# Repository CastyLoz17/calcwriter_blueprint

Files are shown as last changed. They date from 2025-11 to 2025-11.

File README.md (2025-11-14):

A hardware board that emulates keypresses on the keypad matrix of a Sharp EL-W531S II calculator.

## but... why tho?

So uh, once upon a bus ride home, I had a brain blast — a year before, I made math equations that mimicked computer logic ops like `AND`, `OR`, `NOT`, etc. Then I got spicy and added stuff like `SIGN`, `TO_BOOL`, and `EQUALS_TO`. I even hacked together `if` statements and pseudo-loops! but... I couldn’t store variables (tragic).

Eventually I realized I could abuse rounding errors and tangent’s cycly-ness to make storage actually _work_. Huge win. But typing those monster equations by hand? Pain. So the project died (rip scrap paper notes).

Then I wondered if a calculator could be turing complete (spoiler: no 💀), which spiraled into "what if I made it _automate itself_"? Thus, **Calcwriter** was born.

This project was mostly self-sponsored... until I found out that hackclub had blueprint ysws. Then I was like "wait why pay for chaos when I can get _sponsored_ for chaos?"

# Project Overview:

This board is split into two parts, mainly for modularity and also to cut costs for prototyping:

## 1. The logic board:

| Front | Back | Schematics |
| --- | --- | --- |
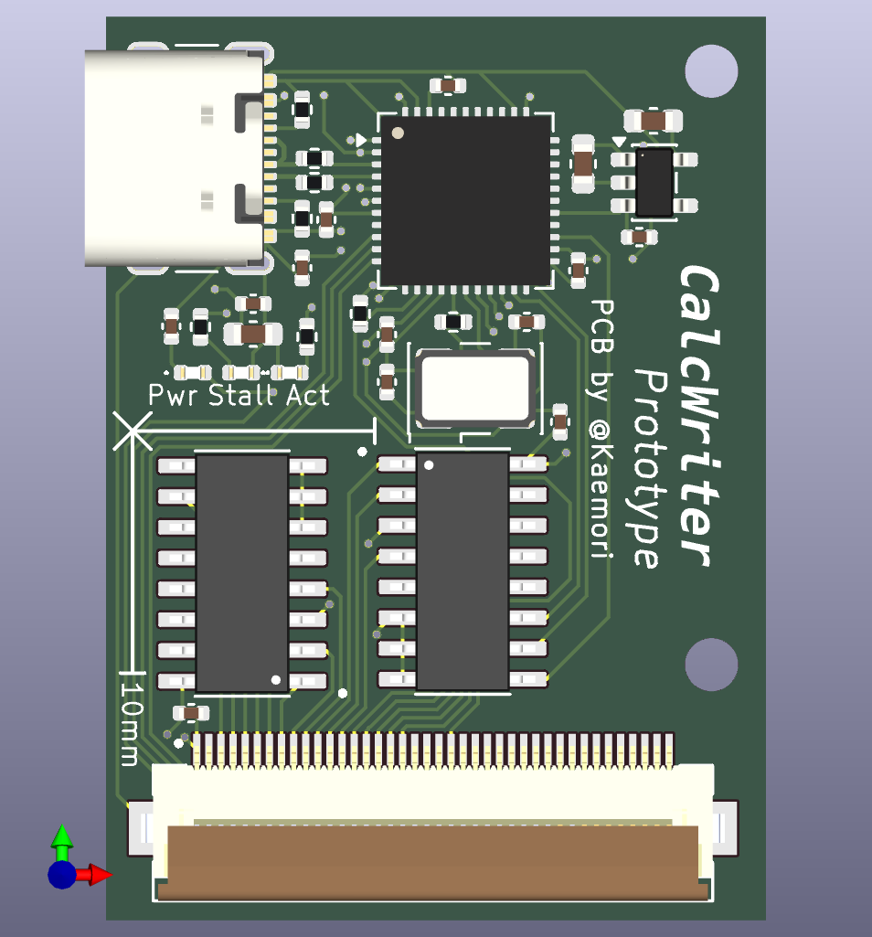
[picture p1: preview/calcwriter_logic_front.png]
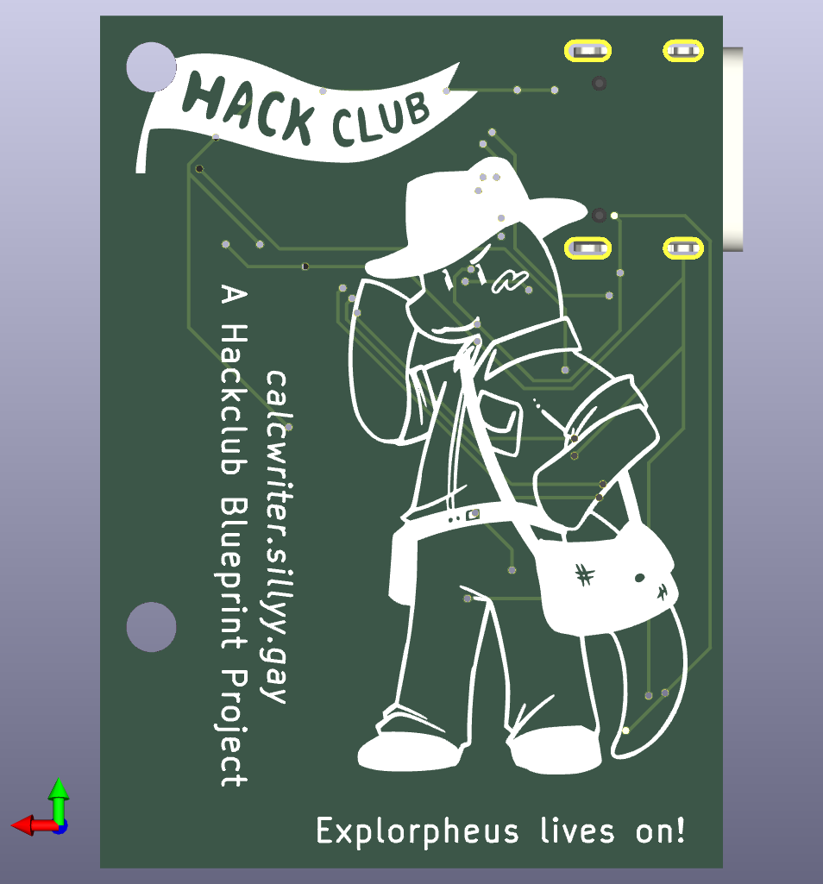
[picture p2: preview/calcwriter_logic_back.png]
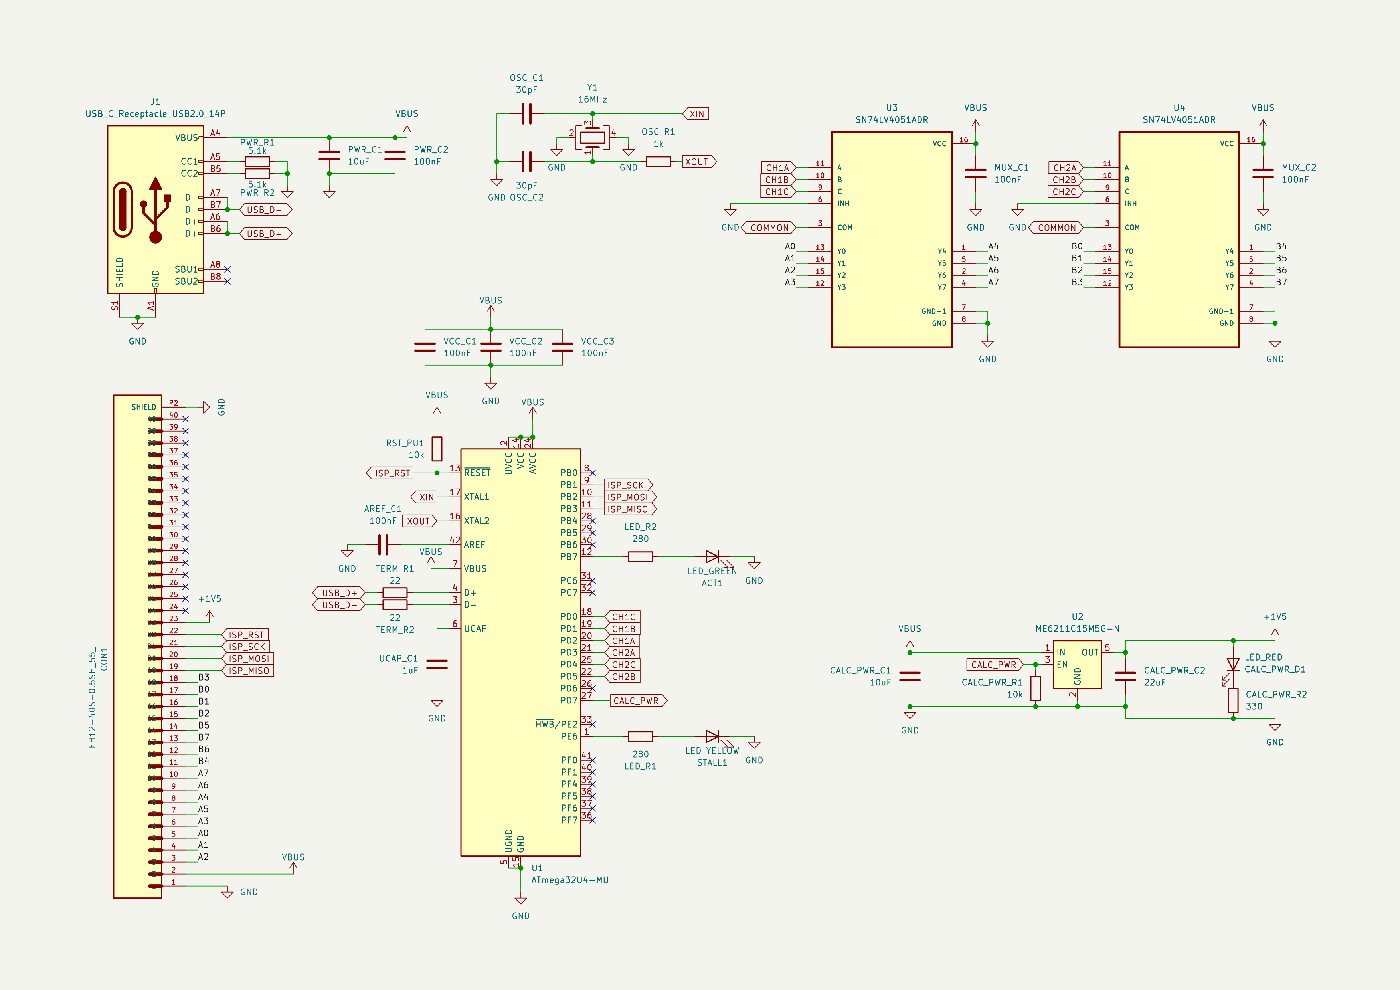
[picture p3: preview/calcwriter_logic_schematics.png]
|  |  |  |

The logic board is the main component, where all the calculations and inputs are actually happening. It is powered by an ATmega32U4 microcontroller and a bunch of SPST Analog Switches (MAX335CWGs) for controlling inputs. Equations will be sent over by the main device through a serial connection, which also powers the board.

## 2. The Interface board:

| Front | Back | Schematics |
| --- | --- | --- |
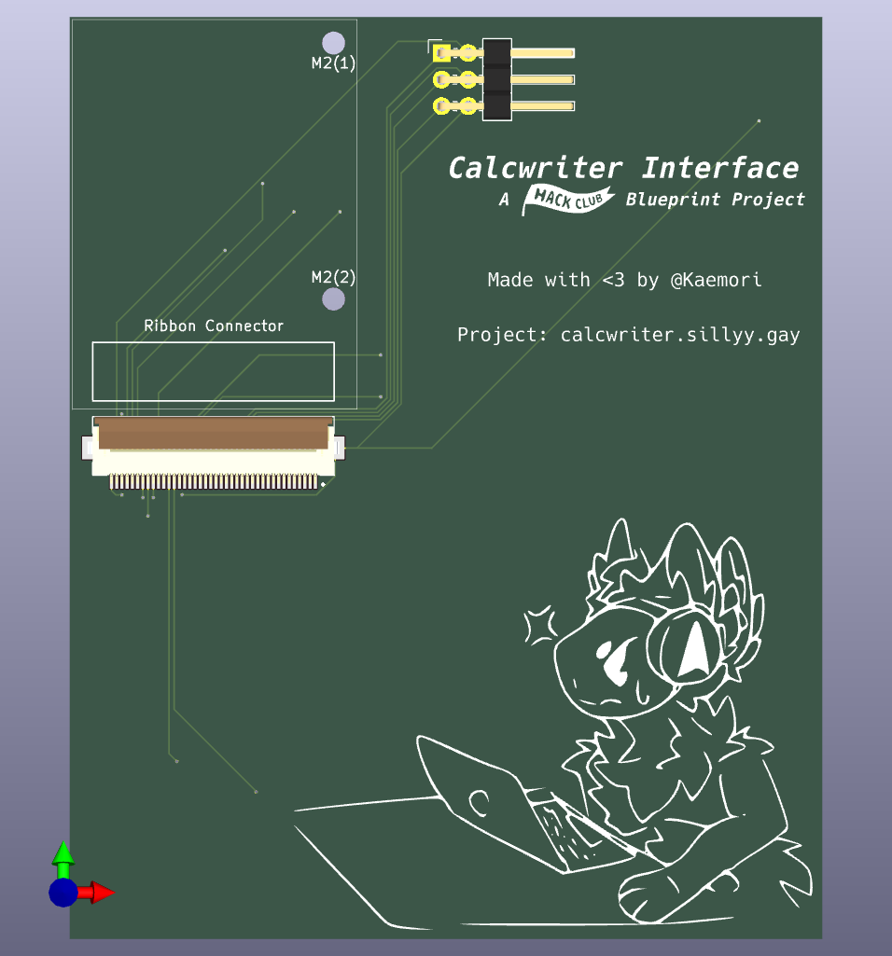
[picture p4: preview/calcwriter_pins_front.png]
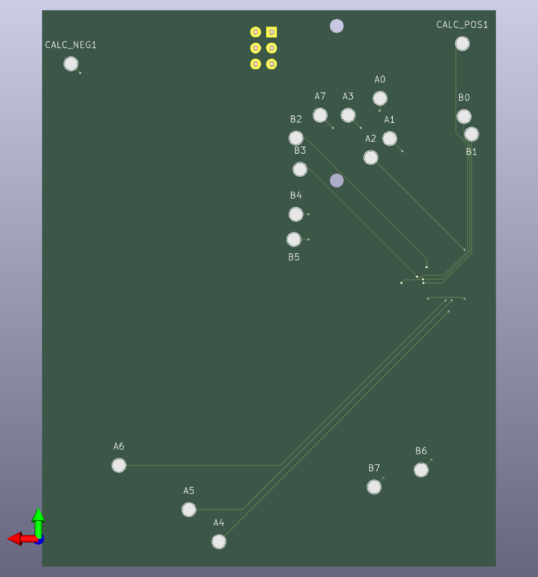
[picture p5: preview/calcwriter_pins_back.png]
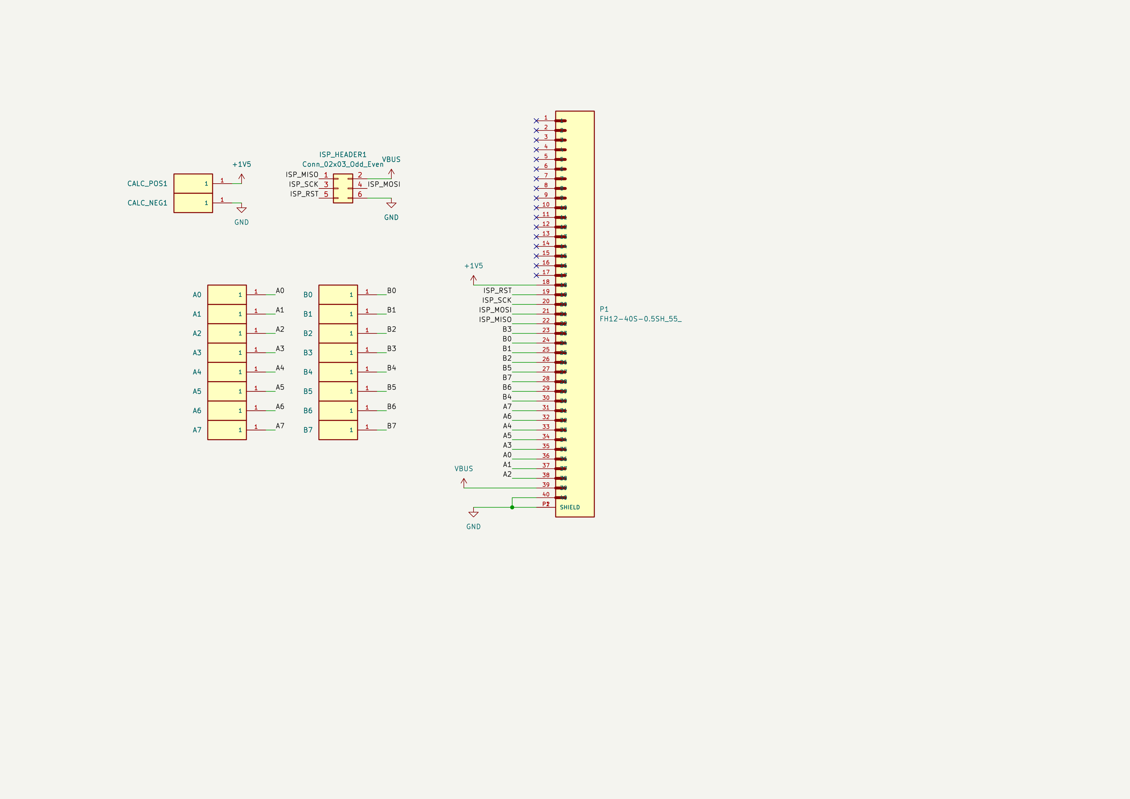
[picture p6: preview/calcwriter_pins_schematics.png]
|  |  |  |

The interface board is the board that connects the logic board to the calculator. It has 31 input pogo pins, as well as 2 power supply pins, each precisely placed such that when the board is placed onto the calculator, the pogo pins connects to the matrix vias of the calculator. The connections are then extended up through a ribbon cable into the logic board for the actual controlling part. The interface board provides power to the calculator, and also provides an ISP interface to program the ATmega32U4. This part is seperated as it allows my logic board to stay as small as possible, and also to make it so that I dont have to waste a lot of money on 4 layers of mostly just empty boards and pogo pins.

# Bill Of Material:

later

TODO: remember to write basic firmware for the board. remember to print out both boards for scale. remember to make a case for the calculator, and the board.

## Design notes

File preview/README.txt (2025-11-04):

This folder contains the PDF of the schematics, as well as the top and bottom view of both boards.

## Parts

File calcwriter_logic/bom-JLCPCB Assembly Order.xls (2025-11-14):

JLCPCB BOM Tool - BOM Matching
BOM name：bom-JLCPCB Assembly Order.xlsx |  |  | Download Time：2025-11-14 10:50:27 |  |  |  | * Our matching results are updated in real-time, but stock and prices may change. If it's been over 24 hours, please re-match before placing your order.
PCB Assembled Qty：5 |  |  | Est. Total Price：14.9566
Your BOM |  |  |  |  | Matched Parts |  |  |  |  |  |  | Order Information
Top Designator | Bottom Designator | Comment | Footprint | JLCPCB Part # | Matches | Part # | Manufacturer | Footprint | Description | Category | Warning | JLCPCB Part # | Product link | Lib Type | Qty | Source | Total Price ($)
ACT1 |  | LED_GREEN | 0402 |  | Select by Customer | NCD0402G1 | Foshan NationStar Optoelectronics | 0402 | -30℃~+85℃ 130° 2.6V~3.6V 20mA 270mcd 515nm~530nm 520nm 72mW Emerald Green 0402 LED Indication - Discrete ROHS | LED Indication - Discrete |  | C130723 | https://jlcpcb.com/partdetail/142012-NCD0402G1/C130723 | Extended | 6 | 6 JLCPCB | 0.2358
AREF_C1,MUX_C1,MUX_C2,PWR_C2,VCC_C1,VCC_C2,VCC_C3 |  | 100nF | 0402 |  | Select by Customer | CL05B104KO5NNNC | Samsung Electro-Mechanics | 0402 | 100nF 16V X7R ±10% 0402 Multilayer Ceramic Capacitors MLCC - SMD/SMT ROHS | Multilayer Ceramic Capacitors MLCC - SMD/SMT | 1.There may be multiple types of parts, but one type of part has been matched. Please check.; | C1525 | https://jlcpcb.com/partdetail/1877-CL05B104KO5NNNC/C1525 | Basic | 14 | 14 JLCPCB | 0.0168
CALC_PWR_C1,PWR_C1 |  | 10uF | 0603 |  | Select by Customer | CL10A106MQ8NNNC | Samsung Electro-Mechanics | 0603 | 10uF 6.3V X5R ±20% 0603 Multilayer Ceramic Capacitors MLCC - SMD/SMT ROHS | Multilayer Ceramic Capacitors MLCC - SMD/SMT | 1.There may be multiple types of parts, but one type of part has been matched. Please check.; | C1691 | https://jlcpcb.com/partdetail/2043-CL10A106MQ8NNNC/C1691 | Extended | 20 | 20 JLCPCB | 0.092
CALC_PWR_C2 |  | 22uF | 0603 |  | Select by System | CL10A226MQ8NRNC | Samsung Electro-Mechanics | 0603 | 22uF 6.3V X5R ±20% 0603 Multilayer Ceramic Capacitors MLCC - SMD/SMT ROHS | Multilayer Ceramic Capacitors MLCC - SMD/SMT |  | C59461 | https://jlcpcb.com/partdetail/60514-CL10A226MQ8NRNC/C59461 | Basic | 2 | 2 JLCPCB | 0.0174
CALC_PWR_D1 |  | LED_RED | 0402 |  | Select by Customer | NCD0402R1 | Foshan NationStar Optoelectronics | 0402 | -30℃~+85℃ 1.6V~2.6V 130° 25mA 30mcd 615nm~635nm 630nm 65mW Red 0402 LED Indication - Discrete ROHS | LED Indication - Discrete |  | C130719 | https://jlcpcb.com/partdetail/142008-NCD0402R1/C130719 | Extended | 7 | 7 JLCPCB | 0.2471
CALC_PWR_R1,RST_PU1 |  | 10k | 0402 |  | Select by Customer | 0402WGF1002TCE | UNI-ROYAL(Uniroyal Elec) | 0402 | -55℃~+155℃ 10kΩ 50V 62.5mW Thick Film Resistor ±1% ±100ppm/℃ 0402 Chip Resistor - Surface Mount ROHS | Chip Resistor - Surface Mount | 1.There may be multiple types of parts, but one type of part has been matched. Please check.; | C25744 | https://jlcpcb.com/partdetail/26487-0402WGF1002TCE/C25744 | Basic | 4 | 4 JLCPCB | 0.0024
CALC_PWR_R2 |  | 330 | 0402 |  | Select by Customer | 0402WGF3300TCE | UNI-ROYAL(Uniroyal Elec) | 0402 | -55℃~+155℃ 330Ω 50V 62.5mW Thick Film Resistor ±1% ±100ppm/℃ 0402 Chip Resistor - Surface Mount ROHS | Chip Resistor - Surface Mount | 1.The comment (0402WGF3300TCE) of this part does not match the one (330) provided in your BOM. Please confirm; | C25104 | https://jlcpcb.com/partdetail/25847-0402WGF3300TCE/C25104 | Basic | 2 | 2 JLCPCB | 0.0014
CON1 |  | FH12-40S-0.5SH_55_ | HRS_FH12-40S-0.5SH_55_ |  | Select by Customer | FH12-40S-0.5SH(55) | HRS(Hirose) | SMD,P=0.5mm,卧贴 | -40℃~+85℃ 0.3mm 0.5mm 2mm 40P Bottom Contact Gold Hinged Lid Phosphor Bronze Surface Mount, Right Angle SMD,P=0.5mm,Surface Mount，Right Angle FFC, FPC (Flat Flexible) Connector Assemblies ROHS | FFC, FPC (Flat Flexible) Connector Assemblies | 1.The comment (FH12-40S-0.5SH(55)) of this part does not match the one (FH12-40S-0.5SH_55_) provided in your BOM. Please confirm; | C202114 | https://jlcpcb.com/partdetail/HRS_Hirose-FH12_40S_0_5SH_55/C202114 | Extended | 2 | 2 JLCPCB | 1.302
J1 |  | USB_C_Receptacle_USB2.0_14P | USB_C_Receptacle_GCT_USB4105-xx-A_16P_TopMnt_Horizontal |  | Select by Customer | TYPE-C16PIN | SHOU HAN | SMD | -40℃~+85℃ 1 10,000 Cycles 16P 30V 3A Black Female Surface Mount, Right Angle Type-C SMD USB Connectors ROHS | USB Connectors |  | C393939 | https://jlcpcb.com/partdetail/SHOUHAN-TYPEC16PIN/C393939 | Extended | 2 | 2 JLCPCB | 0.1288
LED_R1,LED_R2 |  | 280 | 0402 |  | Select by Customer | 0402WGF2800TCE | UNI-ROYAL(Uniroyal Elec) | 0402 | -55℃~+155℃ 280Ω 50V 62.5mW Thick Film Resistor ±1% ±100ppm/℃ 0402 Chip Resistor - Surface Mount ROHS | Chip Resistor - Surface Mount | 1.The comment (0402WGF2800TCE) of this part does not match the one (280) provided in your BOM. Please confirm; | C423200 | https://jlcpcb.com/partdetail/416150-0402WGF2800TCE/C423200 | Extended | 20 | 20 JLCPCB | 0.014
OSC_C1,OSC_C2 |  | 30pF | 0402 |  | Select by Customer | 0402CG300J500NT | FH (Guangdong Fenghua Advanced Tech) | 0402 | 30pF 50V C0G ±5% 0402 Multilayer Ceramic Capacitors MLCC - SMD/SMT ROHS | Multilayer Ceramic Capacitors MLCC - SMD/SMT |  | C1570 | https://jlcpcb.com/partdetail/1922-0402CG300J500NT/C1570 | Extended | 20 | 20 JLCPCB | 0.022
OSC_R1 |  | 1k | 0402 |  | Select by System | 0402WGF1001TCE | UNI-ROYAL(Uniroyal Elec) | 0402 | -55℃~+155℃ 1kΩ 50V 62.5mW Thick Film Resistor ±1% ±100ppm/℃ 0402 Chip Resistor - Surface Mount ROHS | Chip Resistor - Surface Mount |  | C11702 | https://jlcpcb.com/partdetail/12256-0402WGF1001TCE/C11702 | Basic | 2 | 2 JLCPCB | 0.0012
PWR_R1,PWR_R2 |  | 5.1k | 0402 |  | Select by System | 0402WGF5101TCE | UNI-ROYAL(Uniroyal Elec) | 0402 | -55℃~+155℃ 5.1kΩ 50V 62.5mW Thick Film Resistor ±1% ±100ppm/℃ 0402 Chip Resistor - Surface Mount ROHS | Chip Resistor - Surface Mount |  | C25905 | https://jlcpcb.com/partdetail/26648-0402WGF5101TCE/C25905 | Basic | 4 | 4 JLCPCB | 0.002
STALL1 |  | LED_YELLOW | 0402 |  | Select by Customer | NCD0402O1 | Foshan NationStar Optoelectronics | 0402 | -30℃~+85℃ 1.6V~2.6V 130° 20mcd~45mcd 25mA 598nm~610nm 65mW Discrete Diode Orange 0402 LED Indication - Discrete ROHS | LED Indication - Discrete |  | C130720 | https://jlcpcb.com/partdetail/142009-NCD0402O1/C130720 | Extended | 7 | 7 JLCPCB | 0.2814
TERM_R1,TERM_R2 |  | 22 | 0402 |  | Select by Customer | 0402WGF220JTCE | UNI-ROYAL(Uniroyal Elec) | 0402 | -55℃~+155℃ 22Ω 50V 62.5mW Thick Film Resistor ±1% ±100ppm/℃ 0402 Chip Resistor - Surface Mount ROHS | Chip Resistor - Surface Mount | 1.The comment (0402WGF220JTCE) of this part does not match the one (22) provided in your BOM. Please confirm; | C25092 | https://jlcpcb.com/partdetail/25835-0402WGF220JTCE/C25092 | Basic | 4 | 4 JLCPCB | 0.0024
U1 |  | ATmega32U4-A | QFN-44-1EP_7x7mm_P0.5mm_EP5.15x5.15mm |  | Select by Customer | ATMEGA32U4-MU | Microchip Tech | VQFN-44-EP(7x7) | 10bit 16MHz 2.7V~5.5V 26 32KB AVR FLASH VQFN-44-EP(7x7) Microcontrollers (MCU/MPU/SOC) ROHS | Microcontrollers (MCU/MPU/SOC) |  | C112161 | https://jlcpcb.com/partdetail/MicrochipTech-ATMEGA32U4MU/C112161 | Extended | 2 | 2 JLCPCB | 10.239
U2 |  | ME6211C15M5G-N | SOT-23-5 |  | Select by System | ME6211C15M5G-N | MICRONE(Nanjing Micro One Elec) | SOT-23-5 | -40℃~+85℃ 1 1.5V 300mA 6V 70dB@(1kHz) Enable Fixed Positive SOT-23-5 Voltage Regulators - Linear, Low Drop Out (LDO) Regulators ROHS | Voltage Regulators - Linear, Low Drop Out (LDO) Regulators |  | C53100 | https://jlcpcb.com/partdetail/54116-ME6211C15M5GN/C53100 | Extended | 6 | 6 JLCPCB | 0.2862
U3,U4 |  | SN74LV4051ADR | SOIC127P600X175-16N |  | Select by System | SN74LV4051ADR | Texas Instruments | SOIC-16 | -40℃~+85℃ 1 22Ω 2V~5.5V 35MHz 600ps 8:1 SOIC-16 Analog Switches, Multiplexers ROHS | Analog Switches, Multiplexers |  | C128414 | https://jlcpcb.com/partdetail/TexasInstruments-SN74LV4051ADR/C128414 | Extended | 4 | 4 JLCPCB | 0.9764
UCAP_C1 |  | 1uF | 0402 |  | Select by System | CL05A105KA5NQNC | Samsung Electro-Mechanics | 0402 | 1uF 25V X5R ±10% 0402 Multilayer Ceramic Capacitors MLCC - SMD/SMT ROHS | Multilayer Ceramic Capacitors MLCC - SMD/SMT |  | C52923 | https://jlcpcb.com/partdetail/53938-CL05A105KA5NQNC/C52923 | Basic | 2 | 2 JLCPCB | 0.0058
Y1 |  | 16MHz | Crystal_SMD_5032-4Pin_5.0x3.2mm |  | Select by Customer | XL1EL89CSI-111YLC-16M | YXC Crystal Oscillators | SMD5032-4P | -40℃~+85℃ 16MHz 20pF Crystal Oscillator ±10ppm ±20ppm SMD5032-4P Crystals ROHS | Crystals |  | C18214305 | https://jlcpcb.com/partdetail/19392654-XL1EL89CSI_111YLC16M/C18214305 | Extended | 5 | 5 JLCPCB | 1.0825

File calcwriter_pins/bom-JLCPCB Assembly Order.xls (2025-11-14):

JLCPCB BOM Tool - BOM Matching
BOM name：bom-JLCPCB Assembly Order.xlsx |  |  | Download Time：2025-11-14 11:09:23 |  |  |  | * Our matching results are updated in real-time, but stock and prices may change. If it's been over 24 hours, please re-match before placing your order.
PCB Assembled Qty：5 |  |  | Est. Total Price：4.5900
Your BOM |  |  |  |  | Matched Parts |  |  |  |  |  |  | Order Information
Top Designator | Bottom Designator | Comment | Footprint | JLCPCB Part # | Matches | Part # | Manufacturer | Footprint | Description | Category | Warning | JLCPCB Part # | Product link | Lib Type | Qty | Source | Total Price ($)
 | A0,A1,A2,A3,A4,A5,A6,A7,B0,B1,B2,B3,B4,B5,B6,B7,CALC_NEG1,CALC_POS1 | 0965-0-15-20-80-14-11-0 | YZR0156-20033-02 |  | Select by Customer | YZR0156-20033-02 | Xinyangze | - | -20℃~+70℃ 10,000 Cycles 12V 1A 1P 2.8mm 3.3mm 50mΩ Brass Gold Pogo Pin - Pogo Pin Spring Probe Connector ROHS | Pogo Pin Spring Probe Connector | 1.The comment (YZR0156-20033-02) of this part does not match the one (0965-0-15-20-80-14-11-0) provided in your BOM. Please confirm; 2.There may be multiple types of parts, but one type of part has been matched. Please check.; | C7429448 | https://jlcpcb.com/partdetail/Xinyangze-YZR0156_2003302/C7429448 | Extended | 36 | 36 JLCPCB | 4.59

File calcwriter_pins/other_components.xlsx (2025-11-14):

Digi-Key: Shopping Cart
Index | Quantity | Part Number | Manufacturer Part Number | Description | Customer Reference | Available | Backorder | Unit Price | Extended Price USD
1 | 1 | HFK140CT-ND | FH12A-40S-0.5SH(55) | CONN FFC FPC TOP 40POS 0.5MM R/A |  | 1 | 0 | 2.3 | 2.30
2 | 1 | 952-2092-ND | M20-9950345 | CONN HEADER R/A 6POS 2.54MM |  | 1 | 0 | 0.35 | 0.35

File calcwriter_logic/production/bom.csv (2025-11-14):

Designator | Footprint | Quantity | Value | LCSC Part #
ACT1 | 0402 | 1 | LED_GREEN
AREF_C1, MUX_C1, MUX_C2, PWR_C2, VCC_C1, VCC_C2, VCC_C3 | 0402 | 7 | 100nF
CALC_PWR_C1, PWR_C1 | 0603 | 2 | 10uF
CALC_PWR_C2 | 0603 | 1 | 22uF
CALC_PWR_D1 | 0402 | 1 | LED_RED
CALC_PWR_R1, RST_PU1 | 0402 | 2 | 10k
CALC_PWR_R2 | 0402 | 1 | 330
CON1 | HRS_FH12-40S-0.5SH_55_ | 1 | FH12-40S-0.5SH_55_
J1 | USB_C_Receptacle_GCT_USB4105-xx-A_16P_TopMnt_Horizontal | 1 | USB_C_Receptacle_USB2.0_14P
LED_R1, LED_R2 | 0402 | 2 | 280
OSC_C1, OSC_C2 | 0402 | 2 | 30pF
OSC_R1 | 0402 | 1 | 1k
PWR_R1, PWR_R2 | 0402 | 2 | 5.1k
STALL1 | 0402 | 1 | LED_YELLOW
TERM_R1, TERM_R2 | 0402 | 2 | 22
U1 | QFN-44-1EP_7x7mm_P0.5mm_EP5.15x5.15mm | 1 | ATmega32U4-MU
U2 | SOT-23-5 | 1 | ME6211C15M5G-N
U3, U4 | SOIC127P600X175-16N | 2 | SN74LV4051ADR
UCAP_C1 | 0402 | 1 | 1uF
Y1 | Crystal_SMD_5032-4Pin_5.0x3.2mm | 1 | 16MHz

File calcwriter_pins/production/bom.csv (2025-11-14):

Designator | Footprint | Quantity | Value | LCSC Part #
A0, A1, A2, A3, A4, A5, A6, A7, B0, B1, B2, B3, B4, B5, B6, B7, CALC_NEG1, CALC_POS1 | YZR0156-20033-02 | 18 | 0965-0-15-20-80-14-11-0
ISP_HEADER1 | PinHeader_2x03_P2.54mm_Horizontal | 1 | Conn_02x03_Odd_Even
P1 | HRS_FH12-40S-0.5SH_55_ | 1 | FH12-40S-0.5SH_55_

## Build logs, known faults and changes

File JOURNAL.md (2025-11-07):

<!--
  ===================    !!READ THIS NOTICE!!   ====================
  DO NOT edit this file manually. Your changes WILL BE OVERWRITTEN!
  This journal is auto generated and updated by Hack Club Blueprint.
  To edit this file, please edit your journal entries on Blueprint.
  ==================================================================
-->

## 10/25/2025 3 PM - Joined Blueprint! Updated my Blueprint with current progress  

I started this project like two weeks ago as a my first PCB project, and only now did I realize there was a YSWS for this exact thing lmfao.
When I started this project, I hooked up Hackatime to my KiCad, and made a nice little schematic for this, and also started routing this board. The schematic is just an Arduino Micro Pro, connected to three PCF8575s, that then routes into 10 CD4066s. This is then hooked into a common bus and a ribbon connector, which is supposed to short two pins of the matrix at a time. The 10 CD4066s are insane to route, so I'm currently trying to find another SPST chip that isn't a bajillion dollars. This is still an improvement from my previous plan of 90 MOSFET switches for my first prototype! Schematics attached below!



## 10/25/2025 6 PM - Redesigned PCB!  

I did not like the crowded method of having a PCF8575 IC expander that then connects into CD4066s, so I did the logical thing and went hunting for a higher channel capacity SPST switch, which lead me to find the (relatively) cheap MAX335, a chip with 8 seperately controlled SPST switches (double what the CD4066 had, with only 4 SPST switches), and ALSO support daisy chaining (using the SPI interface instead of the I2C interface the PFC8575 used), which halved the amount of analog switch chips I needed, and also removed the need for the PFC8575 chips since everything is daisy-chained! Now I need to actually do routing lmao.
OH YEAH ALSO i added decaps. very silly.
Schematics attached below!


## 10/26/2025 1 PM - Routed the PCB  

This was two days of my life, mostly because of the fact that I have never done anything like this before (not even the "Hello world" of PCBCADing, I skipped the humble LED + Resistor intro and dived DIRECTLY INTO WHATEVER THIS IS!)


My routing is a bit horrible but I managed to get this done at last. I also learnt about the existence of power and ground fills (and how it's SUPPOSED to reduce interference?) so like I used them in the GND and VCC layers of my board!
PCB attached below:


## 10/26/2025 2 PM - Cleaned up the PCB  

I'm writing this in a haste. I redid some of the connections that looked weird or that could be optimized, and stuck the branding on there as well. Reminder to self to start taking measurements and finish the pogo board by today, as well as silkscreen the github urb and credits onto the board.



## 10/27/2025 - Made the second board and cleaned up the PCB (Pt. 2)  

I did all the required measurements for the second interface board that is supposed to make the connection between the calculator and my logic board... even made a script that explores the best possible arrangement for the pins such that there wouldn't be any overlaps between the routing:

Script here:


After that, I read through the devboard tutorial and realized I made many bad PCB mistakes (e.g. not dogbone'ing my vias, caps way bigger than required, yada yada)... so I redid my routing. it still has many problems with it but I'm just so done with PCBing for today:


Maybe I'll tank tonight out and fix up my horrible choices? I don't know... I have a robotics competition tomorrow...  

## 10/28/2025 - Readme'ing and DNSing  

I wrote a nice little readme on my github page, and spent another good portion of today night to make both https://calcwriter.sillyy.gay and http://calcwriter.sillyy.gay redirect to https://github.com/CastyLoz17/calcwriter_blueprint using Cloudfare. This took way too long. I suck at DNS records. This sucks.


note to self to clean up pcb after I return from tomorrow's competition.  

## 10/29/2025 - Swapped Arduino out for SOC  

Title says it all! I swapped the Sparkfun Micro Pro with a SOC (More specifically, the ATmega32U4) to be put directly onto the board! Right now though, its just the schematics only, and I haven't wired the main components yet (e.g. Only connected the USB-C header and crystal oscillator)

Also, before that, I cleaned up my PCB for the... I-don't-even-know-anymore-th time... so theres that!
Tomorrow, I'll work on reworking my old SPST Analog Switches with absolutely horrible wiring, with some new schematics with nets and stuff, connect the SOC to the Analog Switches, and maaaybe start working on connecting the SOC to the main board if I have the time?
I also realized my Interface board was in the wrong orientation, and had to be flipped over. I was SOOOO close to hand-doing it until my lord and savior Keyaan said that I could just move components from one side of the board to the other side, and vice versa. This tip helped me save so much time, I CANNOT thank you enough!
All in all a very long day (Microchip Technologies make HORRIBLE docs), but I'm glad I got things done.  

## 10/30/2025 - Swapped Arduino out for SOC (on the PCB!)  

I have gone TOO long without writing a journal entry, and it's ITCHING ASKJFHAJLFHSDKJFHAL
I've done a LOT in the past 2 days:
- Finished and cleaned up Schematics
- Swapped out the Arduino out for a ATmega32U4
- REwired my PCB because I changed some stuff in the schematics

The following is... TWO WHOLE DAMN DAYS OF WORK!


Next up, I'll optimize the PCB, and then ship this project!
also, say hi to Goober!


p.s. Don't mind the mismatched holes at the top, I forgot to refill copper fills before taking a screenshot and am too lazy to fix.  

## 10/31/2025 - Fixed some mistakes, made vias bigger (for cost efficiency)  

So... apparently my board was not cost-efficient as I had to use 0.15mm via hole sizes, and the blueprint people were not too happy about that. The base via hole size JLC offers is 0.3mm hole size, so I had to go through and change every via to be double its size! AAAAND then I did one final sanity check and realized I have been using a 48 pin chip instead of the 44 pin I should be using, which means I had to redo the SOC since it was the wrong footprint. At long last this (should) be done! unless... I figure out how to remove the last horizontal CD4066 chip somehow? that would make my board way shorter... if only there was a way to employ the GPIO pins... I'll think about this overnight

PCB below!:


## 11/3/2025 - light rerouting and some styling  

explorpheus!



i also did a bit of cleaning up (again), made the board a biiitt shorter and way more appealing. also printed the outline out using my 3d printer and i like the size! thats silly heh
welp theres nothing left to do except writing the github and also some simple blinky firmware and then shipping! 4 days till november 7th and im proud of meh speed!

## 11/7/2025 - complete reroute, cutting costs, shrinking board (and more!)  

below you see 18 hours of work in one screenshot!


for starters, you might see that the board is different. thats because i completely rerouted everything!! after a bit of tinkering on my calculator board with my multimeter, i found out that there were (at least) 8 pairs of vias that are internally connected! and 8 is also how many channels one MAX335 chip offers. this gave me a way to completely remove the 5th chip at the bottom, reducing my board's vertical length and wiring complexity! these newly opened channels also provided me a way to connect the ISP headers AND the calculator power supply directly to the interface board using ribbon cables (_6 + 1 = 7_ channels for this, just about how much channels i freed. that gives me 31 + 7 = 38 channels, 2 less than the 40 that my ribbon cable offers)! this also meant i could remove the pads for the ISP and calculator power, which further reduced the height of my board!

now, all thats left to do is to redo my interface board, do a final sanity check and a cleanup, then update my github! lowkey proud of myself, since this is my _first damn pcb project_ :3

(p.s. i also spent like 3 hours compiling and recompiling my bom after every change, but since that was time i could have saved if i wasnt so anxious, i didnt count it. this 18 hours is just me testing my calculator and redesigning my board)  

## 11/8/2025 - updated schematics!  

the schematics have been updated to reflect the new ribbon cable connections!

i also switched the HORRIBLE schematics i did and replaced the connections with nets! now time for the PCB... siiighhhh

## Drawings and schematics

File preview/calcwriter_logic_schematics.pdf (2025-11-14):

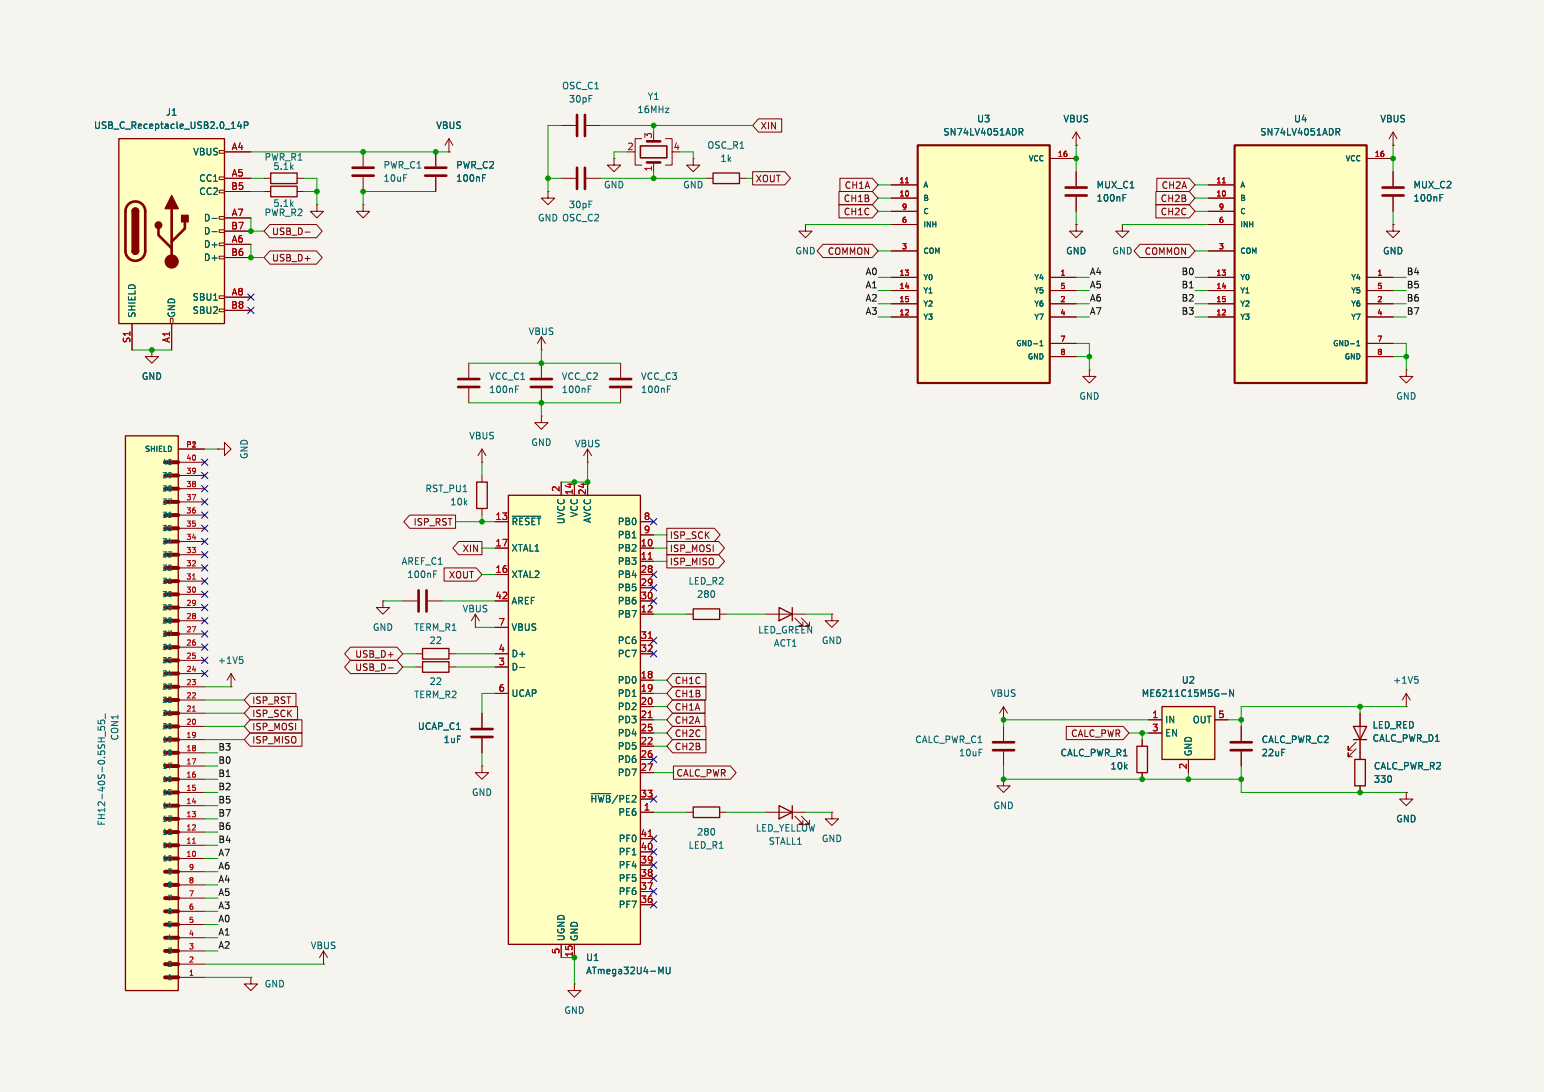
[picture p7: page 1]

5 VCC 14 GND 15 AVCC 24 PB0 8 PB1 9 PB2 10 PB3 11 PB4 28 PB5 29 PB6 30 PB7 12 PC6 31 PC7 32 PD0 18 PD1 19 PD2 20 PD3 21 PD4 25 PD5 22 PD6 26 PD7 27 ~{HWB}/PE233 PE6 1 PF0 41 PF1 40 PF4 39 PF5 38 PF6 37 PF7 36 U1ATmega32U4-MU

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

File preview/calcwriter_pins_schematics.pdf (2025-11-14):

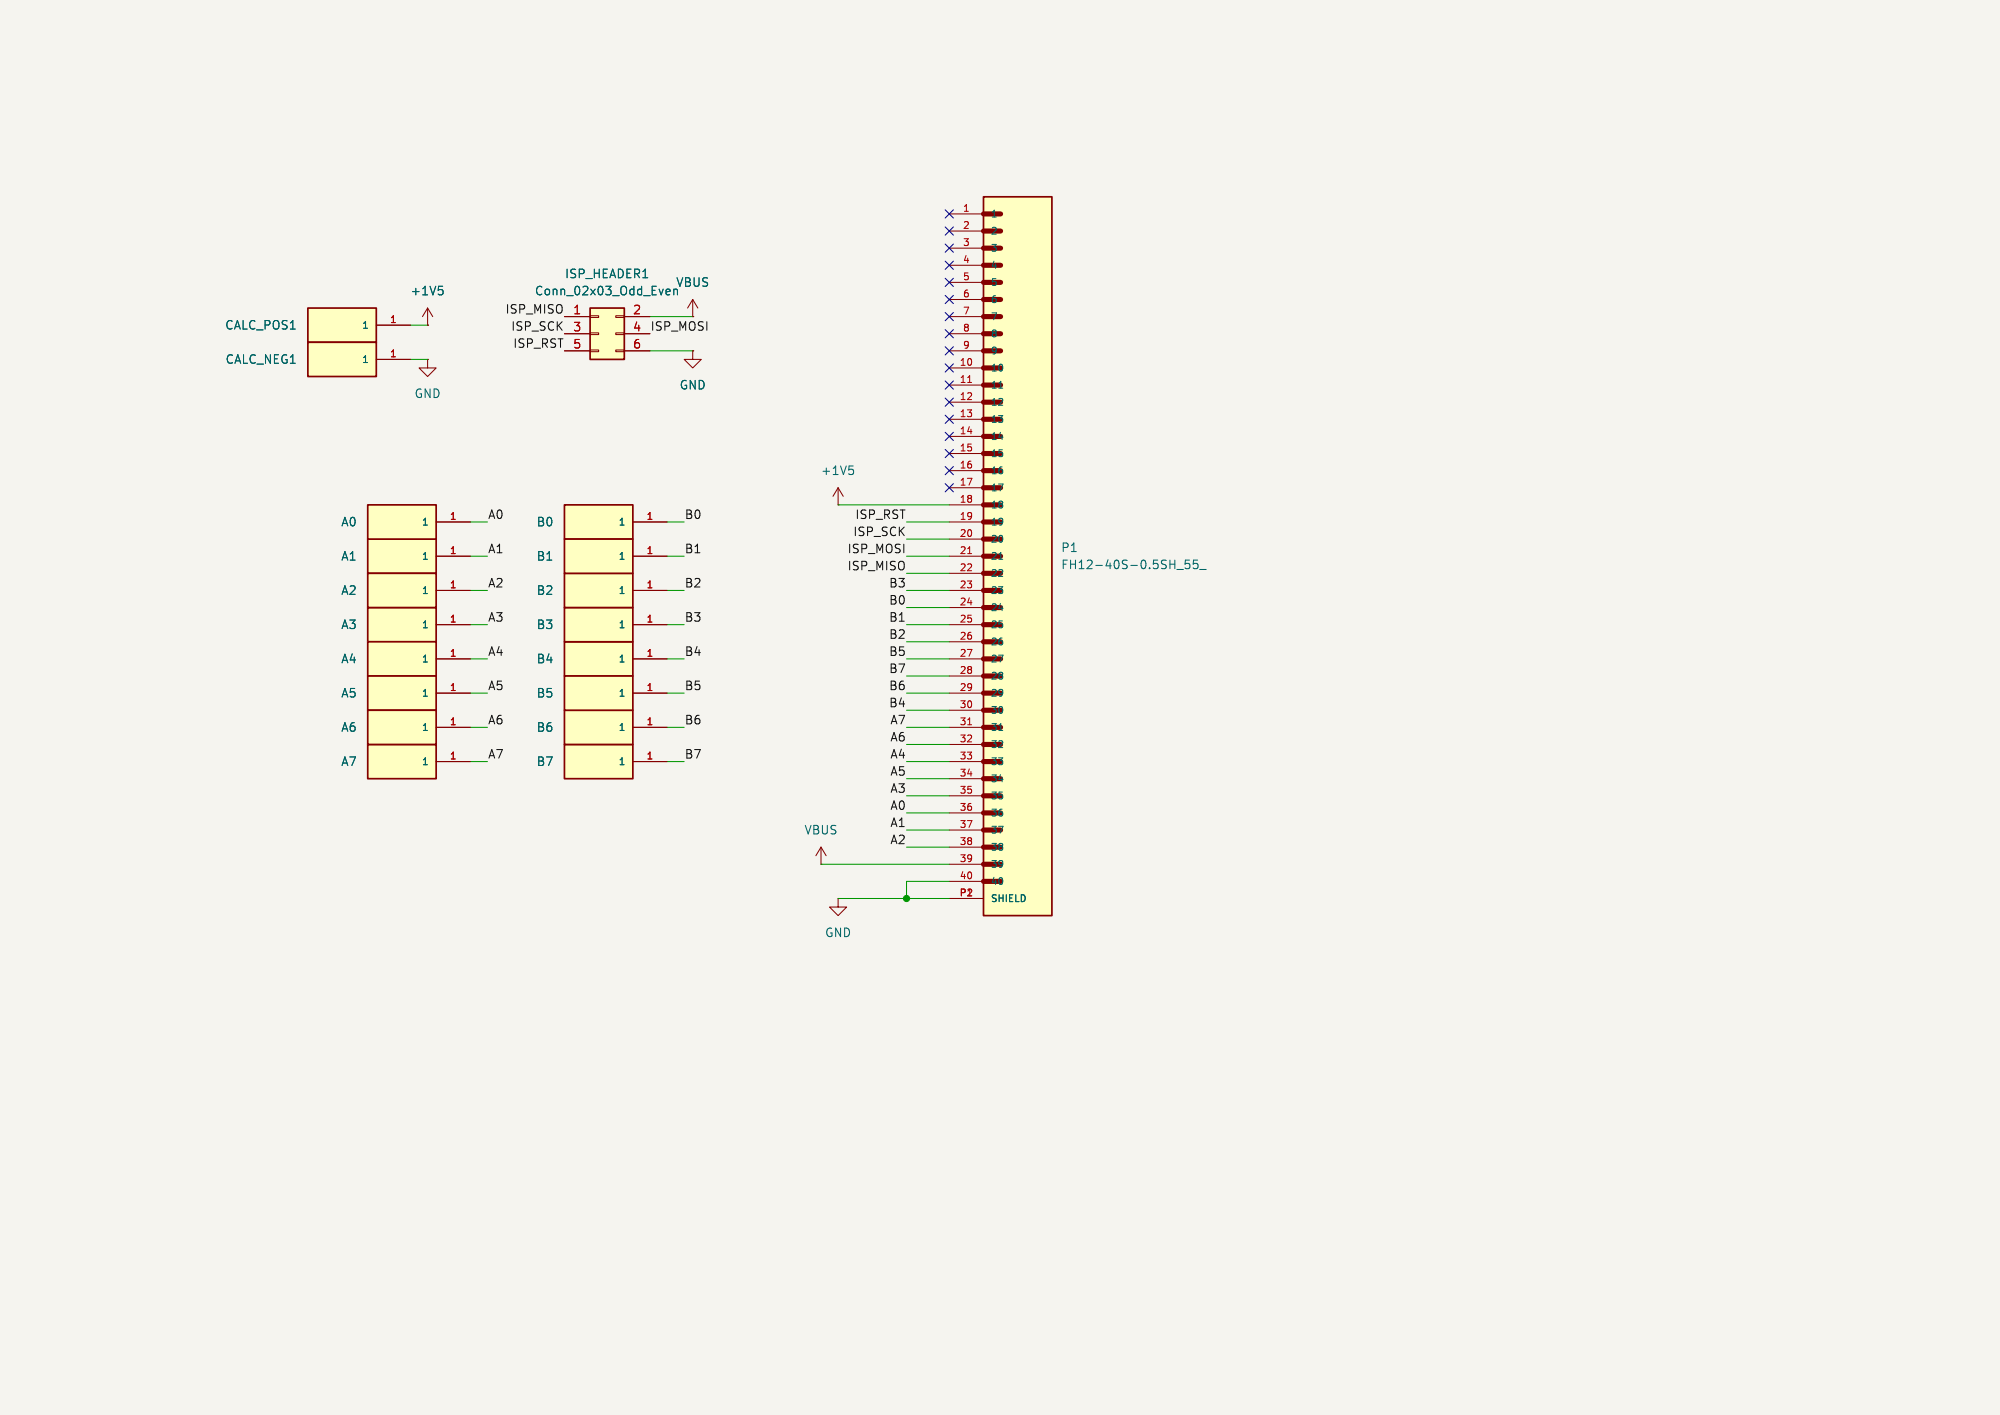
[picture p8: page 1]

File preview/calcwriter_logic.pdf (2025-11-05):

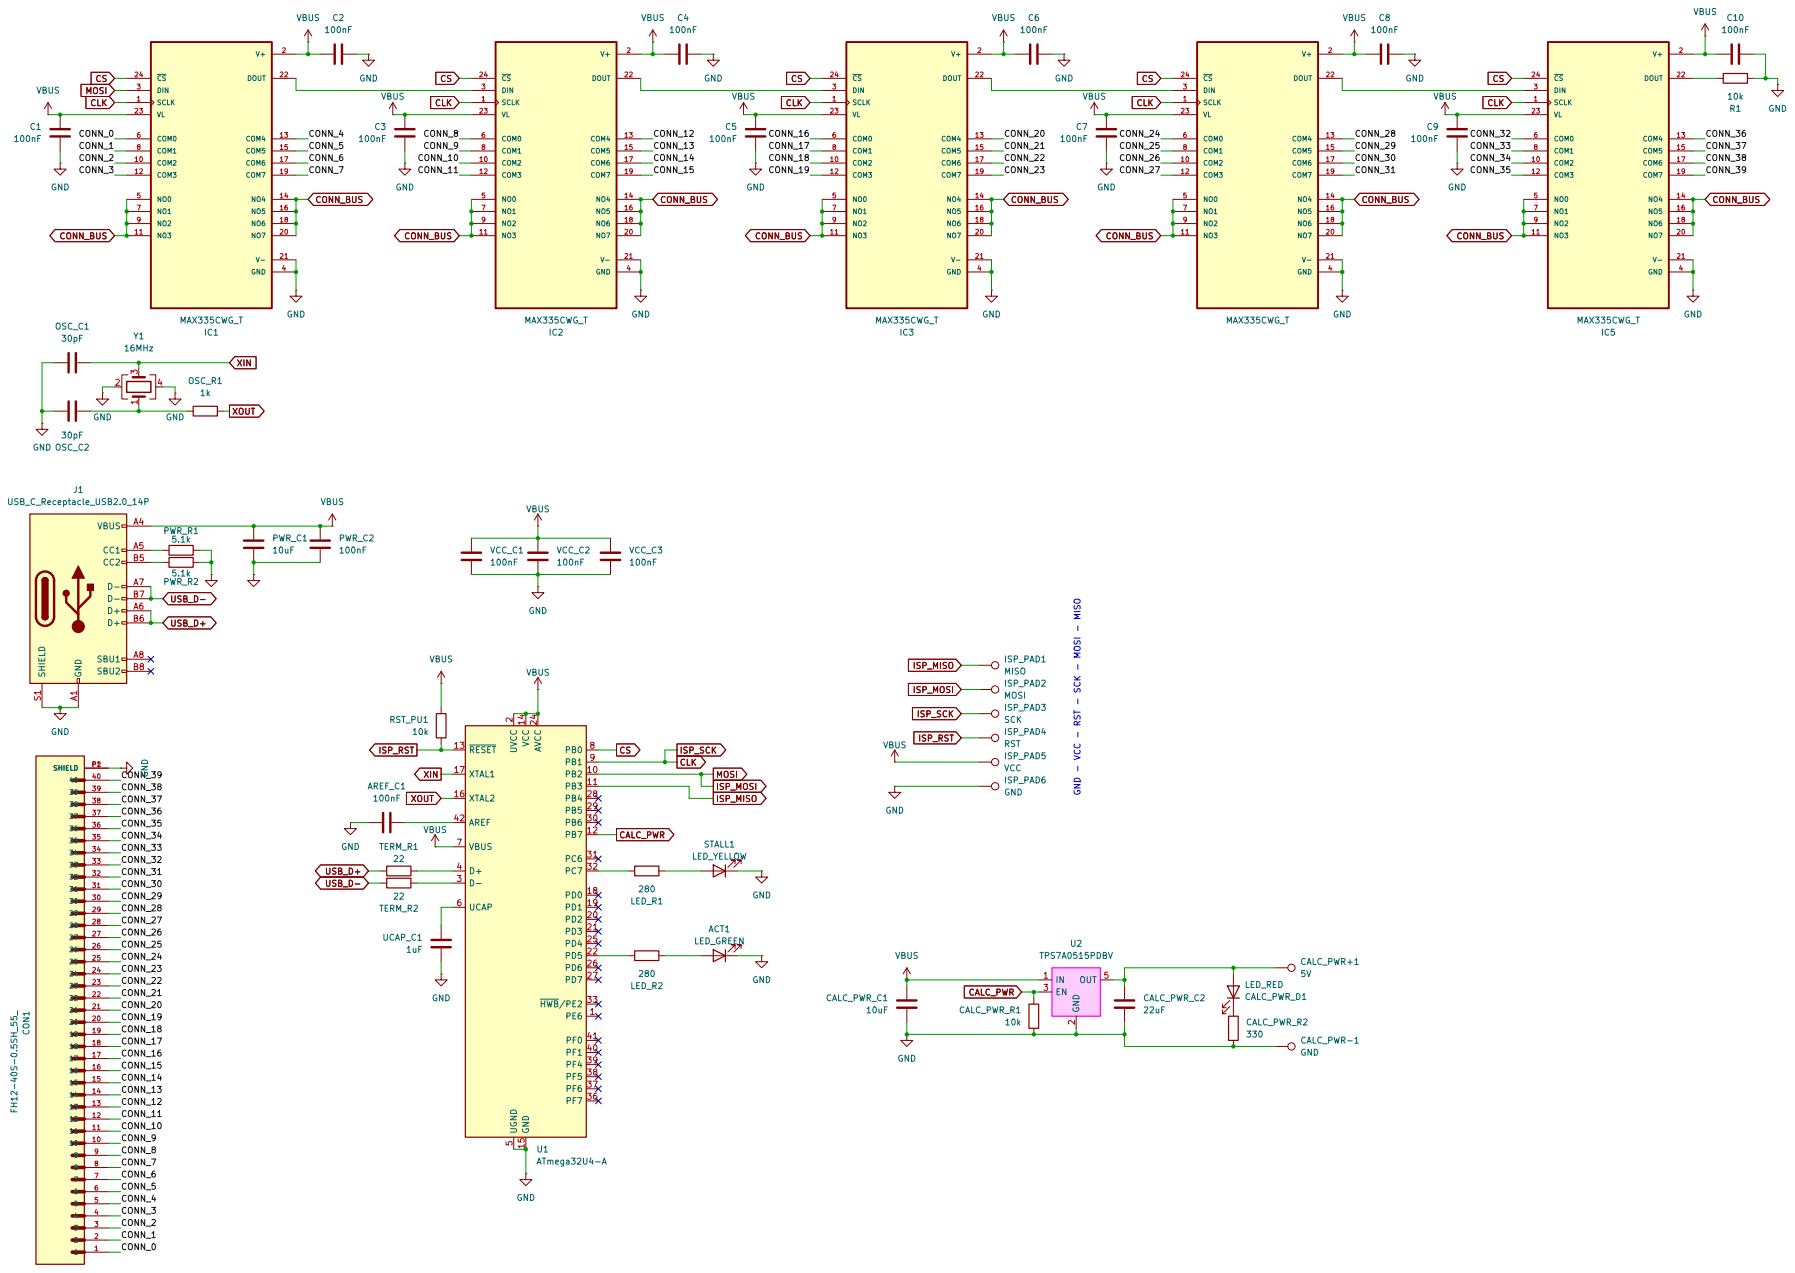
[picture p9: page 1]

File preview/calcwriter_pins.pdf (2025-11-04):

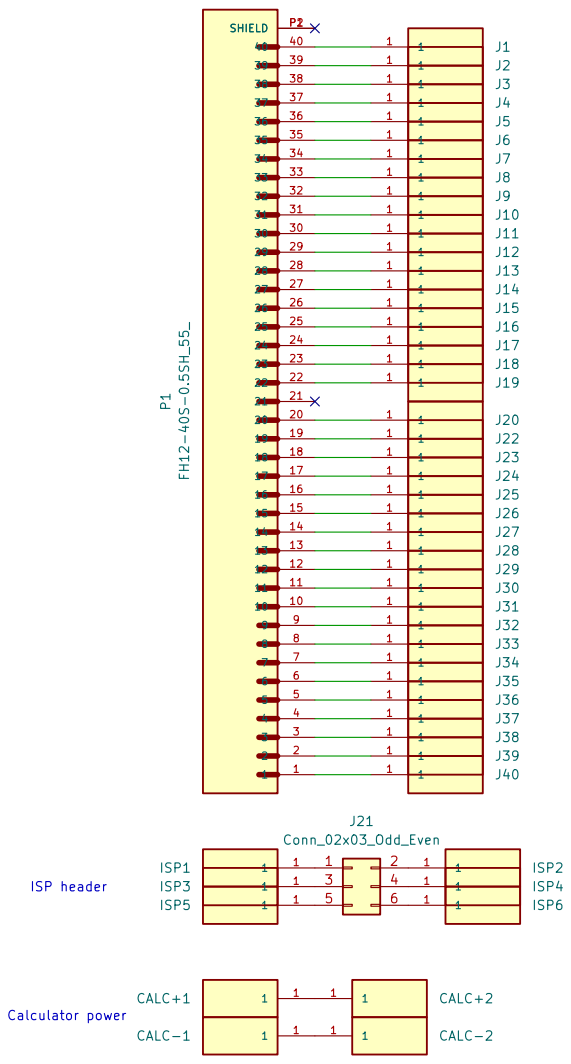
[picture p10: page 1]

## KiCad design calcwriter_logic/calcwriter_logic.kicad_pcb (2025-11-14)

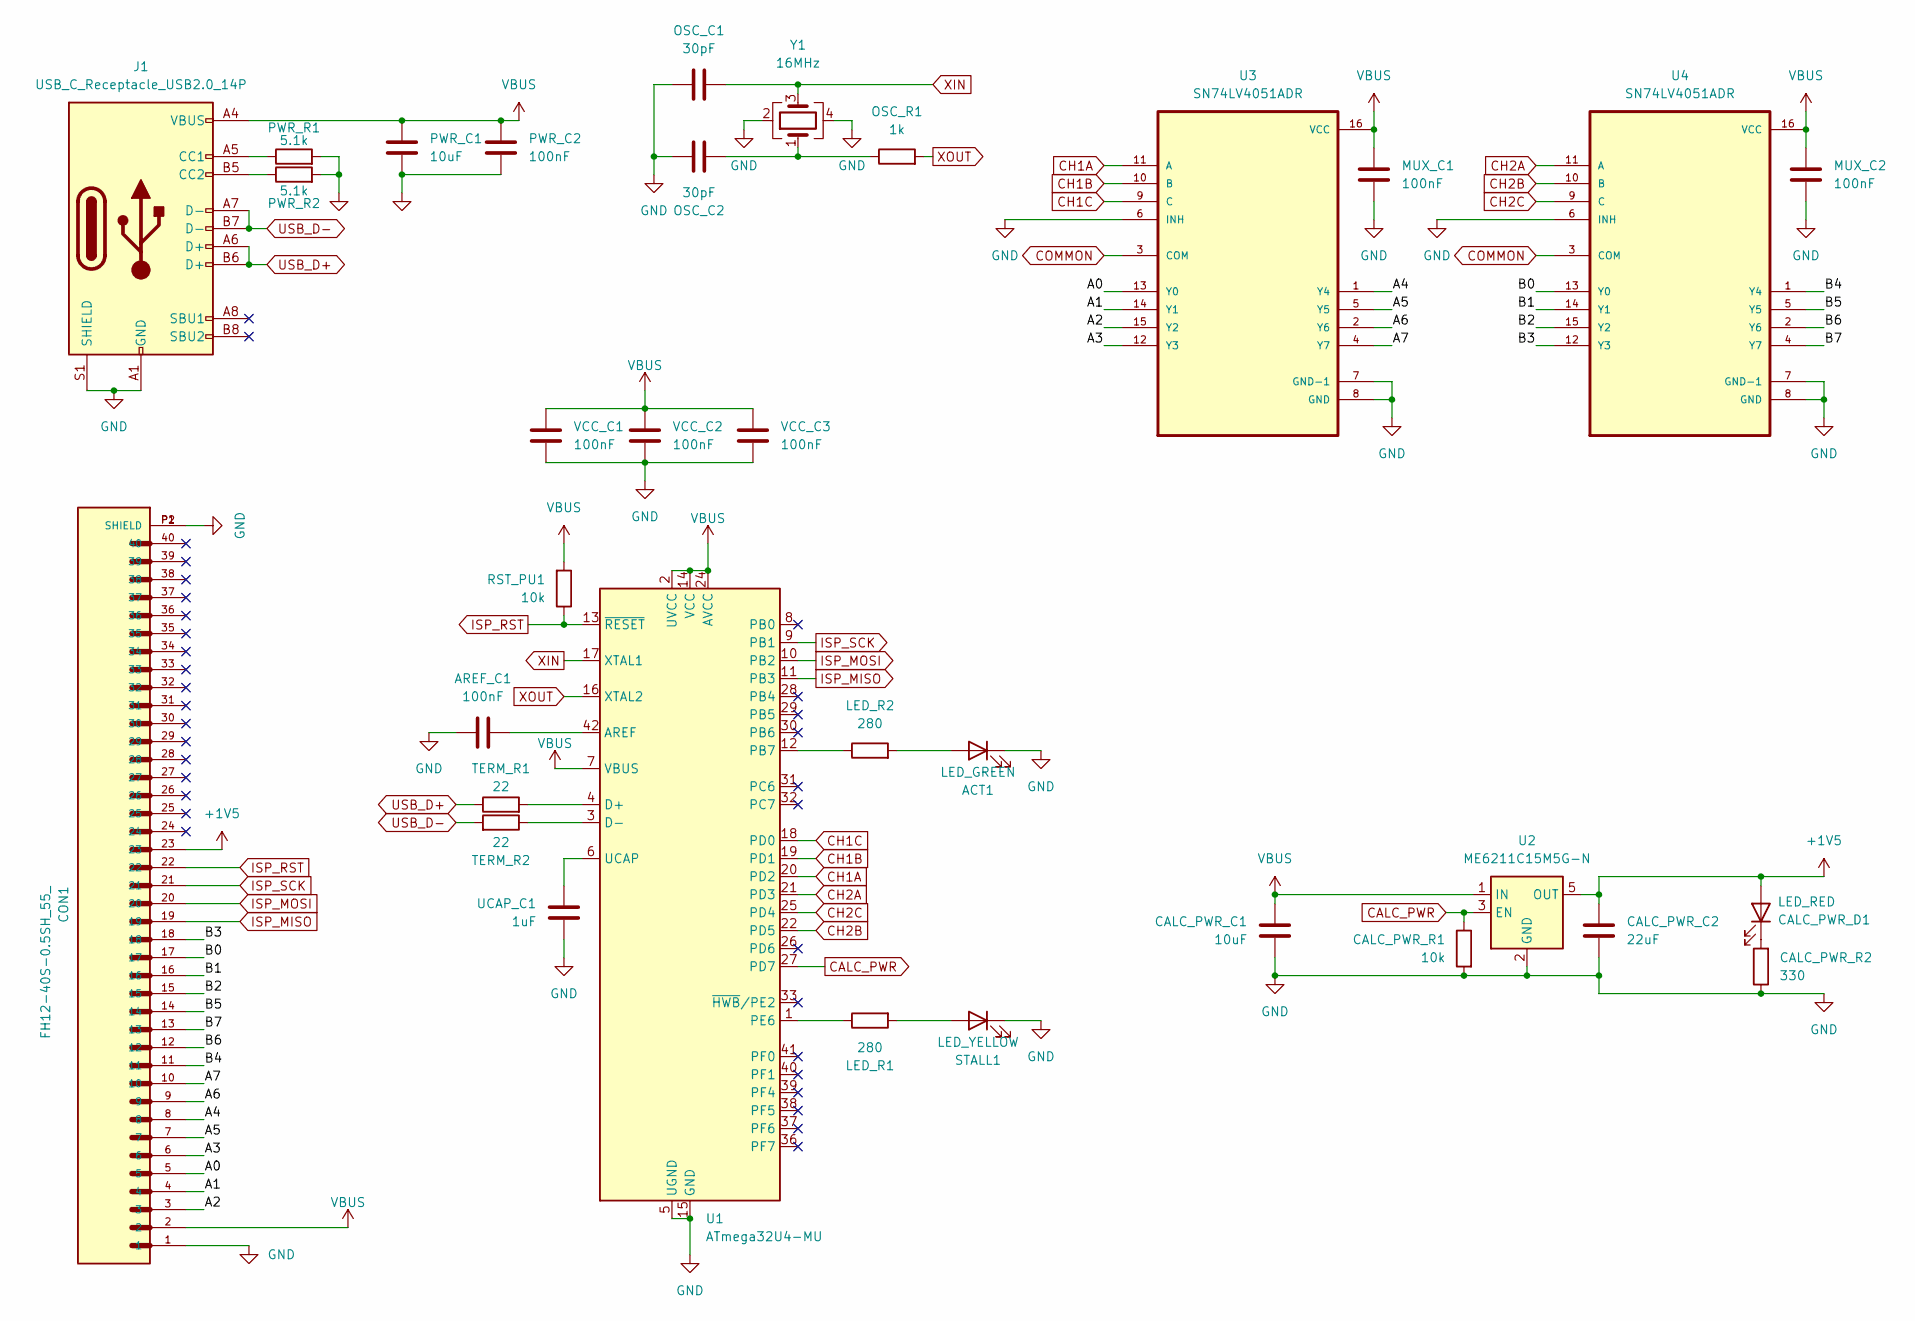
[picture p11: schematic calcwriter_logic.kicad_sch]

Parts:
ACT1: LED_GREEN; LED_0402_1005Metric
AREF_C1: 100nF; C_0402_1005Metric
CALC_PWR_C1: 10uF; C_0603_1608Metric
CALC_PWR_C2: 22uF; C_0603_1608Metric
CALC_PWR_D1: LED_RED; LED_0402_1005Metric
CALC_PWR_R1: 10k; C_0402_1005Metric
CALC_PWR_R2: 330; C_0402_1005Metric
CON1: FH12-40S-0.5SH_55_; HRS_FH12-40S-0.5SH_55_
J1: USB_C_Receptacle_USB2.0_14P; USB_C_Receptacle_GCT_USB4105-xx-A_16P_TopMnt_Horizontal
LED_R1, LED_R2: 280; R_0402_1005Metric
MUX_C1, MUX_C2: 100nF; C_0402_1005Metric
OSC_C1, OSC_C2: 30pF; C_0402_1005Metric
OSC_R1: 1k; R_0402_1005Metric
PWR_C1: 10uF; C_0603_1608Metric
PWR_C2: 100nF; C_0402_1005Metric
PWR_R1, PWR_R2: 5.1k; R_0402_1005Metric
RST_PU1: 10k; R_0402_1005Metric
STALL1: LED_YELLOW; LED_0402_1005Metric
TERM_R1, TERM_R2: 22; R_0402_1005Metric
U1: ATmega32U4-MU; QFN-44-1EP_7x7mm_P0.5mm_EP5.15x5.15mm
U2: ME6211C15M5G-N; SOT-23-5
U3, U4: SN74LV4051ADR; SOIC127P600X175-16N
UCAP_C1: 1uF; C_0402_1005Metric
VCC_C1, VCC_C2, VCC_C3: 100nF; C_0402_1005Metric
Y1: 16MHz; Crystal_SMD_5032-4Pin_5.0x3.2mm

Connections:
+1V5: CALC_PWR_C2.2, CALC_PWR_D1.2 (A), CON1.23, U2.5 (OUT)
/A0: CON1.5, U3.13 (Y0)
/A1: CON1.4, U3.14 (Y1)
/A2: CON1.3, U3.15 (Y2)
/A3: CON1.6, U3.12 (Y3)
/A4: CON1.8, U3.1 (Y4)
/A5: CON1.7, U3.5 (Y5)
/A6: CON1.9, U3.2 (Y6)
/A7: CON1.10, U3.4 (Y7)
/B0: CON1.17, U4.13 (Y0)
/B1: CON1.16, U4.14 (Y1)
/B2: CON1.15, U4.15 (Y2)
/B3: CON1.18, U4.12 (Y3)
/B4: CON1.11, U4.1 (Y4)
/B5: CON1.14, U4.5 (Y5)
/B6: CON1.12, U4.2 (Y6)
/B7: CON1.13, U4.4 (Y7)
CALC_PWR: CALC_PWR_R1.1, U1.27 (PD7), U2.3 (EN)
CH1A: U1.20 (PD2), U3.11 (A)
CH1B: U1.19 (PD1), U3.10 (B)
CH1C: U1.18 (PD0), U3.9 (C)
CH2A: U1.21 (PD3), U4.11 (A)
CH2B: U1.22 (PD5), U4.10 (B)
CH2C: U1.25 (PD4), U4.9 (C)
COMMON: U3.3 (COM), U4.3 (COM)
GND: ACT1.1 (K), AREF_C1.2, CALC_PWR_C1.1, CALC_PWR_C2.1, CALC_PWR_R1.2, CALC_PWR_R2.1, CON1.1, CON1.P1 (SHIELD), CON1.P2 (SHIELD), J1.A1 (GND), J1.A12 (GND), J1.B1 (GND), J1.B12 (GND), J1.S1 (SHIELD), MUX_C1.1, MUX_C2.1, OSC_C1.1, OSC_C2.1, PWR_C1.2, PWR_C2.2, PWR_R1.2, PWR_R2.2, STALL1.1 (K), U1.5 (UGND), U1.15 (GND), U1.23 (GND), U1.35 (GND), U1.43 (GND), U1.45, U2.2 (GND), U3.6 (INH), U3.7 (GND-1), U3.8 (GND), U4.6 (INH), U4.7 (GND-1), U4.8 (GND), UCAP_C1.2, VCC_C1.2, VCC_C2.2, VCC_C3.2, Y1.2, Y1.4
ISP_MISO: CON1.19, U1.11 (PB3)
ISP_MOSI: CON1.20, U1.10 (PB2)
ISP_RST: CON1.22, RST_PU1.1, U1.13 (~RESET)
ISP_SCK: CON1.21, U1.9 (PB1)
unnamed: ACT1.2 (A), LED_R2.2
unnamed: CALC_PWR_D1.1 (K), CALC_PWR_R2.2
unnamed: J1.A5 (CC1), PWR_R1.1
unnamed: J1.B5 (CC2), PWR_R2.1
unnamed: OSC_C2.2, OSC_R1.1, Y1.1
unnamed: LED_R1.2, STALL1.2 (A)
unnamed: AREF_C1.1, U1.42 (AREF)
unnamed: TERM_R1.2, U1.4 (D+)
unnamed: TERM_R2.1, U1.3 (D-)
unnamed: LED_R2.1, U1.12 (PB7)
unnamed: LED_R1.1, U1.1 (PE6)
unnamed: U1.6 (UCAP), UCAP_C1.1
USB_D+: J1.A6 (D+), J1.B6 (D+), TERM_R1.1
USB_D-: J1.A7 (D-), J1.B7 (D-), TERM_R2.2
VBUS: CALC_PWR_C1.2, CON1.2, J1.A4 (VBUS), J1.A9 (VBUS), J1.B4 (VBUS), J1.B9 (VBUS), MUX_C1.2, MUX_C2.2, PWR_C1.1, PWR_C2.1, RST_PU1.2, U1.2 (UVCC), U1.7 (VBUS), U1.14 (VCC), U1.24 (AVCC), U1.34 (VCC), U1.44 (AVCC), U2.1 (IN), U3.16 (VCC), U4.16 (VCC), VCC_C1.1, VCC_C2.1, VCC_C3.1
XIN: OSC_C1.2, U1.17 (XTAL1), Y1.3
XOUT: OSC_R1.2, U1.16 (XTAL2)

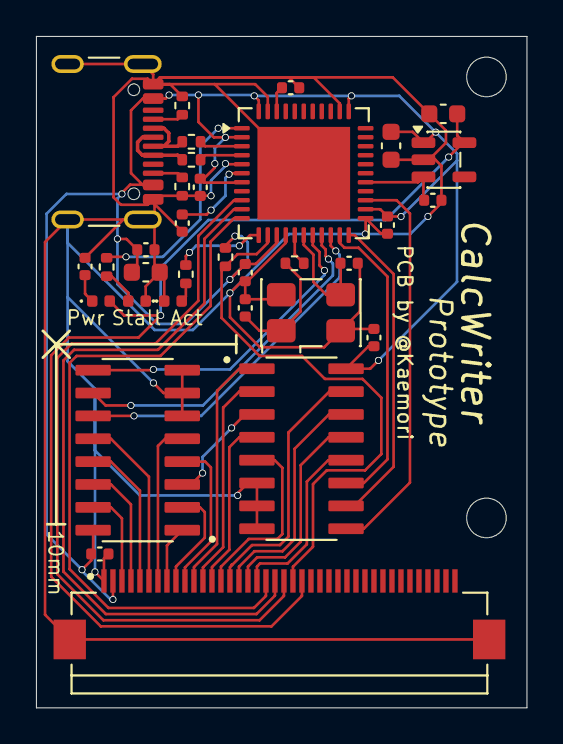
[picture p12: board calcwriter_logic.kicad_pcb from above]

Board: 2 copper layers, 27.2 x 37.3 mm, 35 parts (0 on the bottom side), 47 nets.

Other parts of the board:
SCREW1, SCREW1#2: MountingHole_2.2mm_M2

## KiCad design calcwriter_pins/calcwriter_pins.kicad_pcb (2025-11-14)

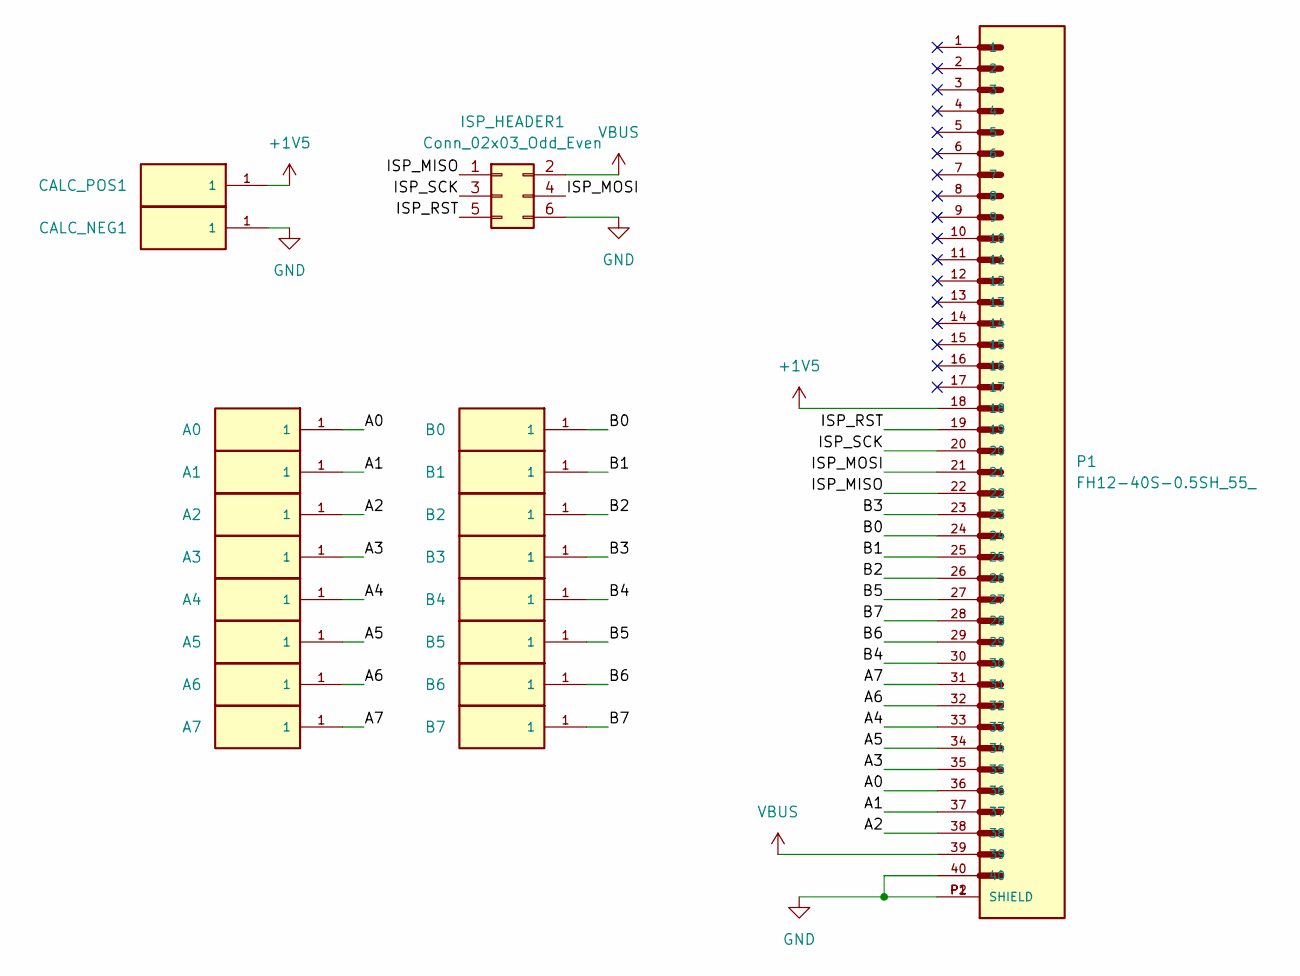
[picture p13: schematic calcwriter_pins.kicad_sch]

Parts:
A0, A1, A2, A3, A4, A5, A6, A7: 0965-0-15-20-80-14-11-0; YZR0156-20033-02; PARTREV 11/26/23
B0, B1, B2, B3, B4, B5, B6, B7: 0965-0-15-20-80-14-11-0; YZR0156-20033-02; PARTREV 11/26/23
CALC_NEG1: 0965-0-15-20-80-14-11-0; YZR0156-20033-02; PARTREV 11/26/23
CALC_POS1: 0965-0-15-20-80-14-11-0; YZR0156-20033-02; PARTREV 11/26/23
ISP_HEADER1: Conn_02x03_Odd_Even; PinHeader_2x03_P2.54mm_Horizontal
P1: FH12-40S-0.5SH_55_; HRS_FH12-40S-0.5SH_55_

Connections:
+1V5: CALC_POS1.1, P1.18
/A0: A0.1, P1.36
/A1: A1.1, P1.37
/A2: A2.1, P1.38
/A3: A3.1, P1.35
/A4: A4.1, P1.33
/A5: A5.1, P1.34
/A6: A6.1, P1.32
/A7: A7.1, P1.31
/B0: B0.1, P1.24
/B1: B1.1, P1.25
/B2: B2.1, P1.26
/B3: B3.1, P1.23
/B4: B4.1, P1.30
/B5: B5.1, P1.27
/B6: B6.1, P1.29
/B7: B7.1, P1.28
/ISP_MISO: ISP_HEADER1.1, P1.22
/ISP_MOSI: ISP_HEADER1.4, P1.21
/ISP_RST: ISP_HEADER1.5, P1.19
/ISP_SCK: ISP_HEADER1.3, P1.20
GND: CALC_NEG1.1, ISP_HEADER1.6, P1.40, P1.P1 (SHIELD), P1.P2 (SHIELD)
VBUS: ISP_HEADER1.2, P1.39

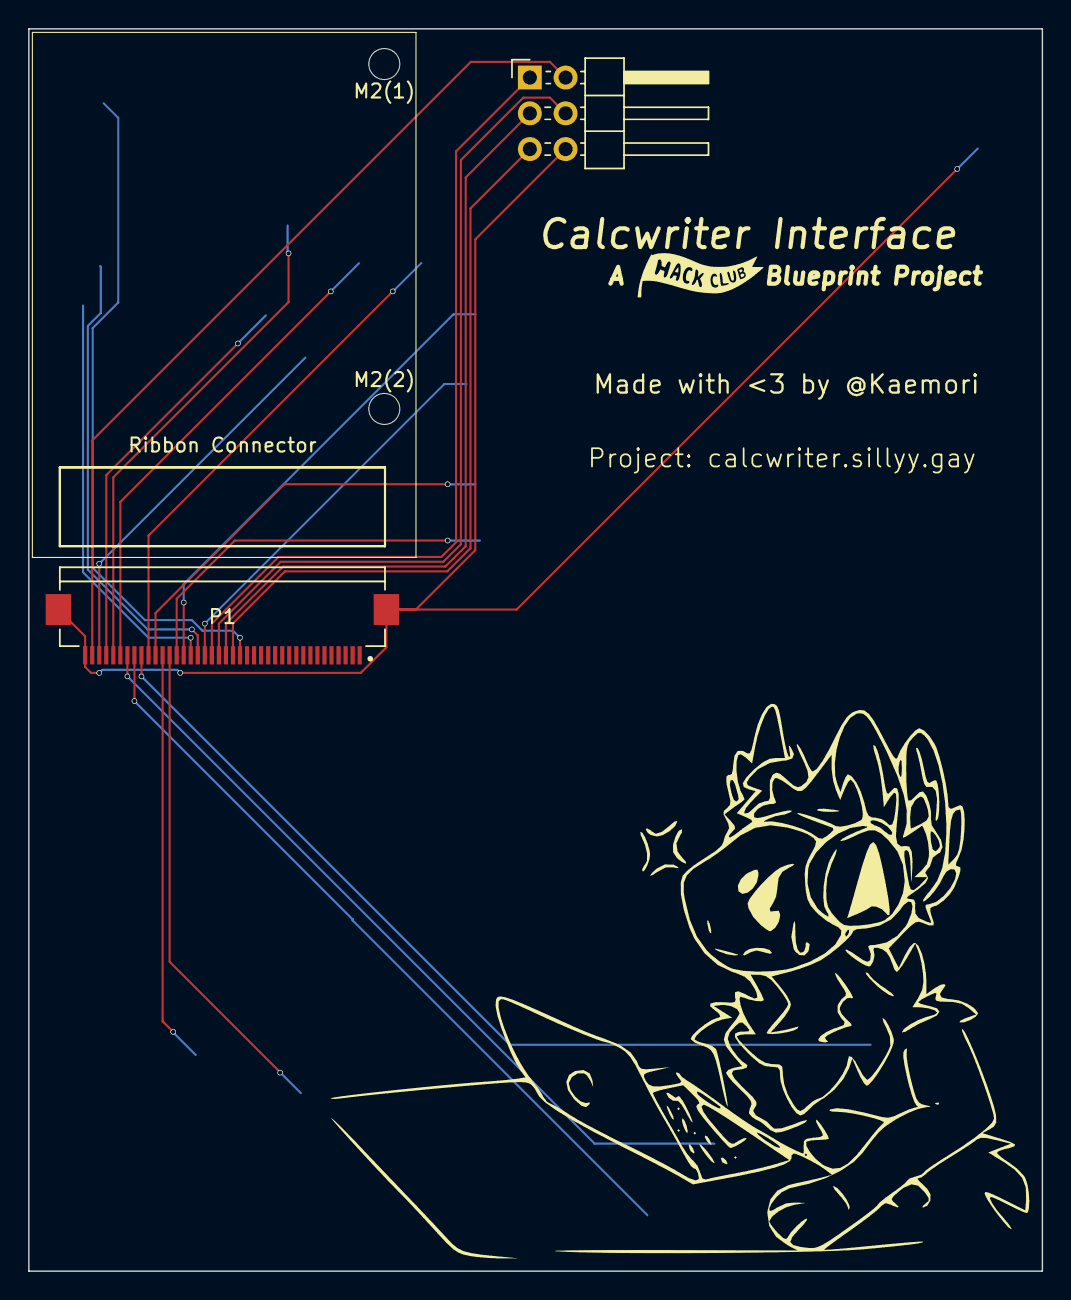
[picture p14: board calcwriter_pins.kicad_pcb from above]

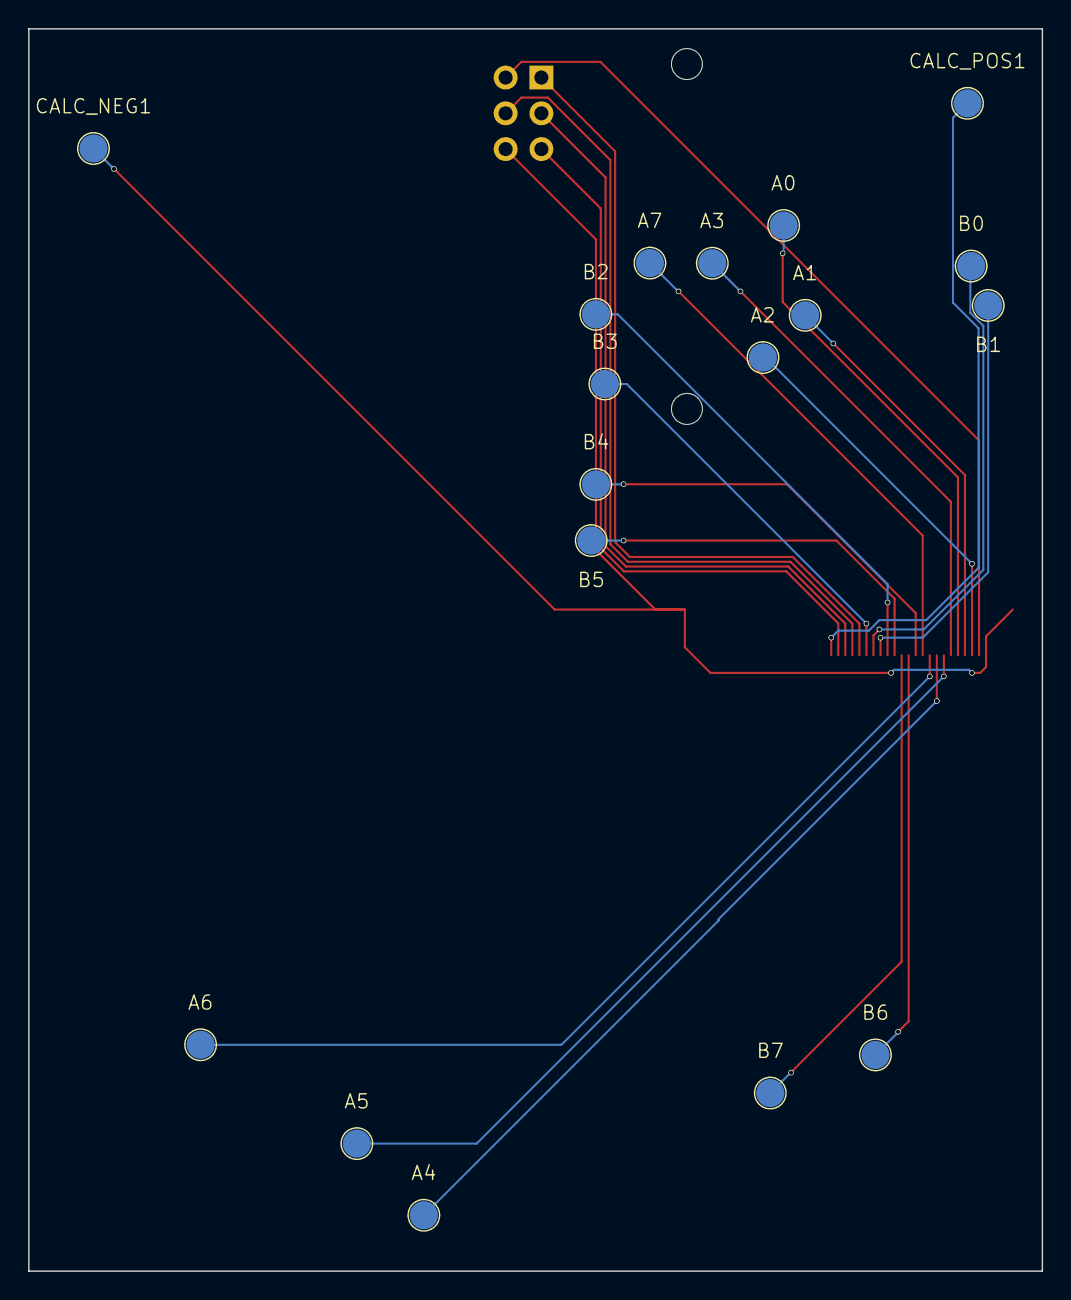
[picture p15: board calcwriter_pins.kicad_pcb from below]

Board: 2 copper layers, 72.0 x 88.2 mm, 22 parts (18 on the bottom side), 23 nets.

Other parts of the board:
SCREW1, SCREW1#2: MountingHole_2.2mm_M2

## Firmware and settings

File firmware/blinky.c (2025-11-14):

#include <avr/io.h>
#include <util/delay.h>

int main(void)
{
    // outputs
    DDRD |= (1 << PD7);
    DDRE |= (1 << PE6);
    DDRB |= (1 << PB7);

    // turn on calc power and stall led
    PORTD |= (1 << PD7);
    PORTE |= (1 << PE6);

    while (1)
    {
        // blinks act led
        PORTB ^= (1 << PB7);
        _delay_ms(1000);
    }
}

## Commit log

2025-11-03 Revise logic and interface board descriptions
    Updated specifications for the logic and interface boards, including changes to the powering microcontroller and additional details about the interface board's functionality.
2025-11-05 Revise README with BOM and updated images
    Updated the README with new images and a detailed Bill of Materials (BOM). Consolidated TODO items and improved formatting.
2025-11-05 Updated logic board schematics
2025-11-05 Updated schematics
2025-11-05 Fix image source for interface board in README
    Updated image source for the interface board section in README.
2025-11-11 did a thing (need to update_
    [bom.csv, calcwriter_logic.kicad_pcb, calcwriter_logic.kicad_sch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]
2025-11-14 did another thing AAAAAAAAAAAAAAAAAAA
    [BOM.csv, bom.csv, calcwriter_logic.kicad_pcb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]
2025-11-14 i should like ship now
    [bom-JLCPCB Assembly Order.xls, other_components.xlsx]
